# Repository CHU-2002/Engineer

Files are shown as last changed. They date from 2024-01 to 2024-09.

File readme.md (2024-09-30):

Most documents are written in Chinese and being translated to English by Google translation.

You will view a typical match in the following URL:[第57场 南方科技大学 ARTINX战队 vs华中科技大学 狼牙战队 RoboMaster 2023 超级对抗赛·区域赛（南部赛区）_哔哩哔哩_bilibili](https://www.bilibili.com/video/BV1iW4y197rk/?spm_id_from=333.788&vd_source=ce4e24e3ceb99b7799902f6719e723f6), in which the "Engineer" robot is No.2 of bule side.

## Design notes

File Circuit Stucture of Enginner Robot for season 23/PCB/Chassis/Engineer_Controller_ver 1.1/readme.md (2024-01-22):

Engineering master control update:

ver 1.0: Fixed the problem of 2482 being difficult to solder

 Fixed the problem of two LDOs connected in parallel

 Added slow start

 Added two can controllers

 Try to separate the power ground and signal ground

Ver 1.1: Fixed the problem of source-drain inversion during power-on slow start

Added silk

Be opened by Altium Designer

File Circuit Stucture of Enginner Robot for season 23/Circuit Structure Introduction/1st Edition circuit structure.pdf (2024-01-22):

## GH1.25-2p

## Tanks chain

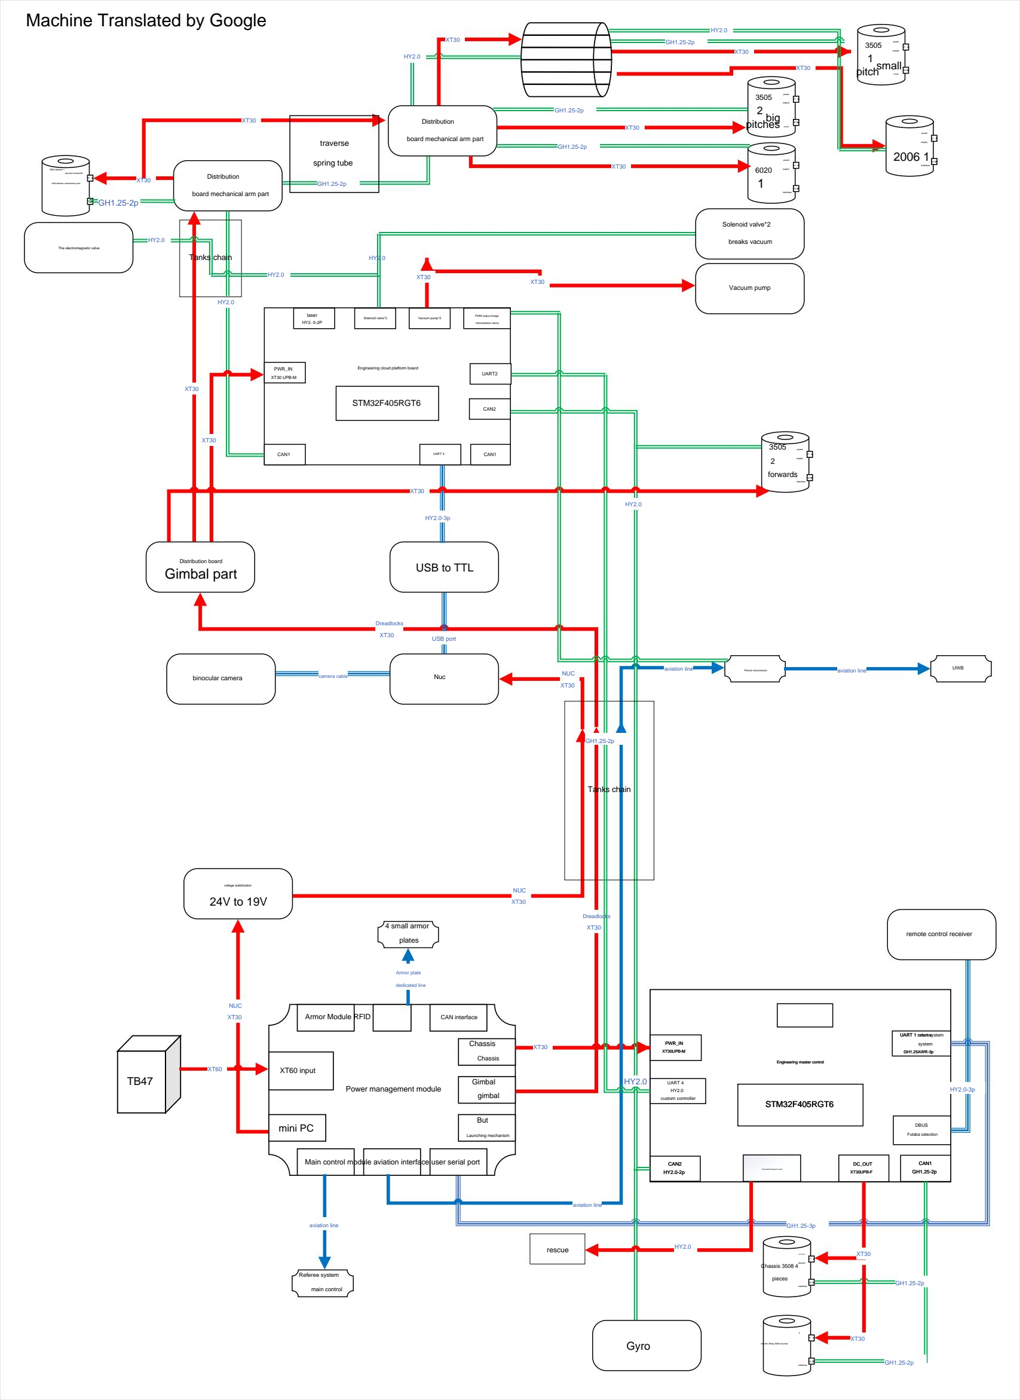
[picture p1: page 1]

XT30 UPB-M

HY2. 0-2P

PWM output image

transmission servo

CAN1

PWR_IN | UART2

laser

CAN2

CAN1

interface

source

3505 electric 1 source horizontal

shift electric connection port

interface

interface

interface

mouth

mouth

interface

### Chassis

CAN interface

Launching mechanism

### Armor Module RFID

### But

### XT60 input Gimbal

### gimbal

Chassis

### Main control module aviation interface user serial port

### 4 small armor

### plates

power

supply

power

supply

power

supply

power

supply

electricity

power

supply

2

electric lifting 3508 sources

HY2.0

Referee system

main control

Picture transmission | UWB

GH1.25-2p

HY2.0

HY2.0

GH1.25-2p

HY2.0

XT30

XT30

XT30

XT30

XT30

XT30

HY2.0

aviation line

camera cable
XT30

Dreadlocks

HY2.0

XT30

XT30

GH1.25-2p

GH1.25-2p

NUC

Dreadlocks

USB port

HY2.0-3p

GH1.25-3p

XT60

GH1.25-2p

aviation line

XT30

XT30

XT30

XT30

Armor plate

dedicated line

XT30

NUC

HY2.0-3p

aviation line NUC

HY2.0

GH1.25-2p

XT30

HY2.0

aviation line

XT30

XT30

XT30

GH1.25-2p

HY2.0

XT30

XT30

# mini PC

## STM32F405RGT6

### rescue

## Tanks chain

## traverse

## spring tube

# Gimbal part

# Gyro

Distribution board | USB to TTL

# 24V to 19V

## Power management module

TB47

binocular camera

voltage stabilization

remote control receiver

Solenoid valve*2

breaks vacuum

Distribution

board mechanical arm part

Vacuum pump

Nuc

The electromagnetic valve

Distribution

board mechanical arm part

## STM32F405RGT6

Engineering cloud platform board

H /L

H /L

H /L

H /L

+/-

+/-

+/-

+/-

+/-

+/-

+/-

H /L

+/-

H /L

H /L

H /L

Engineering master control control

3505

3505

6020

UART 4

Solenoid valve*3 | Vacuum pump*2

XT30UPB-M

Futaba selection

XT30UPB-F

XT30UPB-M | GH1.25AWR-3p GH1.25AWR-3p

DBUS

UART 4
HY2.0
custom controller

DC_OUT

PWR_IN

CAN1
GH1.25-2p GH1.25-2p

PWR_IN

CAN2
HY2.0-2p

The electromagnetic valve

UART 1 court referee system system

3505
2

## forwards

2006 1

Chassis 3508 4

pieces

# 1 small pitch

# 2 big pitches

1

# Machine Translated by Google

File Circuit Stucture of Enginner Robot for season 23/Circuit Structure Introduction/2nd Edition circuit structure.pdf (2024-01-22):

## referee system

6020

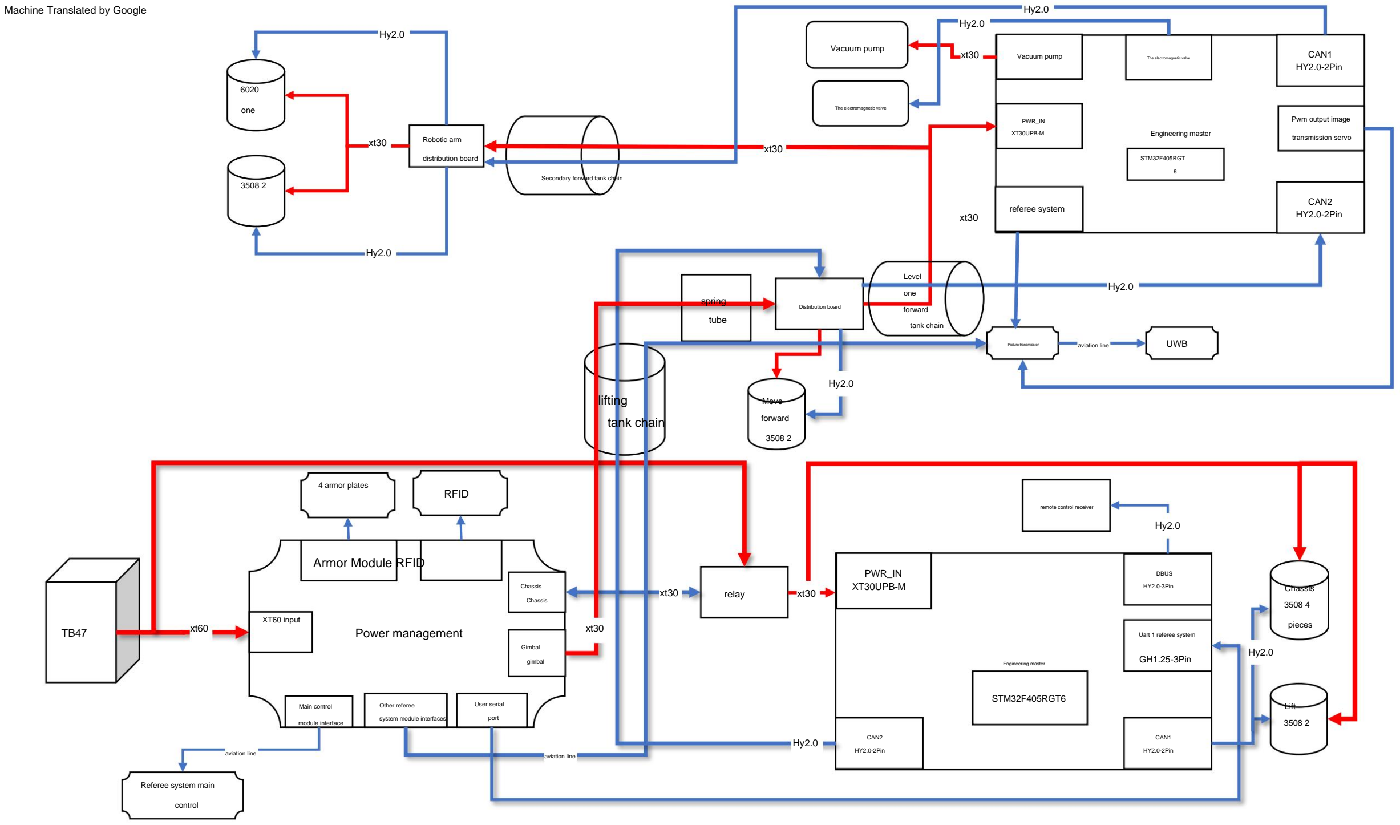
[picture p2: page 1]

## UWB

## spring

## tube

### Robotic arm

### distribution board

### Vacuum pump

### Engineering master

## Lift

3508 2

## Move

## forward

3508 2

## Chassis

3508 4

## pieces

## one

3508 2

The electromagnetic valve

### Pwm output image

### transmission servo

xt30

xt30

xt30

xt30

Picture transmission

## XT60 input

## 4 armor plates

## Referee system main

## control

TB47

The electromagnetic valve

# RFID

## Vacuum pump

# lifting tank chain

# Armor Module RFID

## relay

### Level

### one

### forward

### tank chain

Main control

module interface

Distribution board

Uart 1 referee system

CAN1

HY2.0-2Pin

PWR_IN

CAN2

HY2.0-2Pin

6

remote control receiver

Chassis

Chassis

STM32F405RGT

Other referee

system module interfaces

DBUS

HY2.0-3Pin

Engineering master

aviation line

Gimbal

gimbal

aviation line

XT30UPB-M

aviation line

xt60

Hy2.0

Hy2.0

Hy2.0

Hy2.0

Hy2.0

xt30

Hy2.0

User serial

port

xt30

Hy2.0

## XT30UPB-M

Secondary forward tank chain

Hy2.0

## PWR_IN

xt30

Hy2.0

# Power management

## GH1.25-3Pin

## CAN2 HY2.0-2Pin

## STM32F405RGT6

## CAN1 HY2.0-2Pin

# Machine Translated by Google

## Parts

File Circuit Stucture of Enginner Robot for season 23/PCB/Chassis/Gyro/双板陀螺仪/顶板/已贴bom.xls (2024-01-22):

元件名称 | 元件编号 | 封装规格 | 顶层位号 | 顶层数
2.2uF(225) ±20% 6.3V X5R | C12530 | 0402 | C3, C7 | 2
100KΩ (1003) ±1% | C25741 | 0402 | R8 | 1
150Ω (1500) ±1% | C22808 | 0603 | R1, R2, R3, R4, R5, R6 | 6
ICM-20602 | C97633 | LGA-16_3.0x3.0x0.5P_3+5 | U1 | 1
AO3400A | C20917 | SOT-23-3L | Q1 | 1
1KΩ (1001) ±1% | C11702 | 0402 | R7, R11 | 2
220nF (224) ±10% 16V X7R | C16772 | 0402 | C9 | 1
SC662K-3.3V | C83932 | SOT-23-3 | U3 | 1
QMC5883L | C976032 | LGA-16 | U2 | 1
4.7KΩ (4701) ±1% | C25900 | 0402 | R9, R10 | 2
100nF (104) ±10% 16V X7R | C1525 | 0402 | C1, C2, C4, C5, C6 | 5
4.7uF (475) ±20% 10V X5R | C23733 | 0402 | C8 | 1

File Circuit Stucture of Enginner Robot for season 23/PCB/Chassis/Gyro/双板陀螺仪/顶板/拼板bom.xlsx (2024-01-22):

Comment | Designator | Footprint
1k | R7, R11 | 0402
4.7k | R9, R10 | 0402
100k | R8 | 0402
150R | R1, R2, R3, R4, R5, R6 | 0603
NMOS | Q1 | SOT-23-3
Header 6 | P1, P2 | HEADER 6x1 _ 1.0mm
2.2uF | C3, C7 | 0402
4.7uF | C8 | 0402
100nF | C1, C2, C4, C5, C6 | 0402
220nF | C9 | 0402
ICM20602 | U1 | LGA-16
IST8310 | U2 | LGA16
LDO_SOT23-3 | U3 | SOT-23-3

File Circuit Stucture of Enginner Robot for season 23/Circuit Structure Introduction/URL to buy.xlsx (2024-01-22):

模块名称 | 购买链接
SMC端子/胶壳-电磁阀专用 | 【淘宝】https://m.tb.cn/h.fDcYZsZ?tk=VRfA2onmPXu「SMC电磁阀插头端子SY3120/3220/5120/7120/9120通用电源线束胶壳」 点击链接直接打开
光电传感器 | 【淘宝】https://m.tb.cn/h.fveGomt?tk=DKkI2onFeCM「M4M5M6M8微型激光漫反射光电开关可调可见光红外线感应传感器24v」 点击链接直接打开
激光测距（这一版车没有用到） | 【淘宝】https://m.tb.cn/h.fDcg0qm?tk=HwWN2onEhlG「正点原子串口激光测距模块MS53L0M MS53L1M距离传感器ToF测距仪」 点击链接直接打开
坦克链 | 【淘宝】https://m.tb.cn/h.fveNS0r?tk=8aMq2onlpT3「尼龙塑料钢铝拖链坦克链条静音桥式全封闭机械机床电缆保护穿线槽」 点击链接直接打开

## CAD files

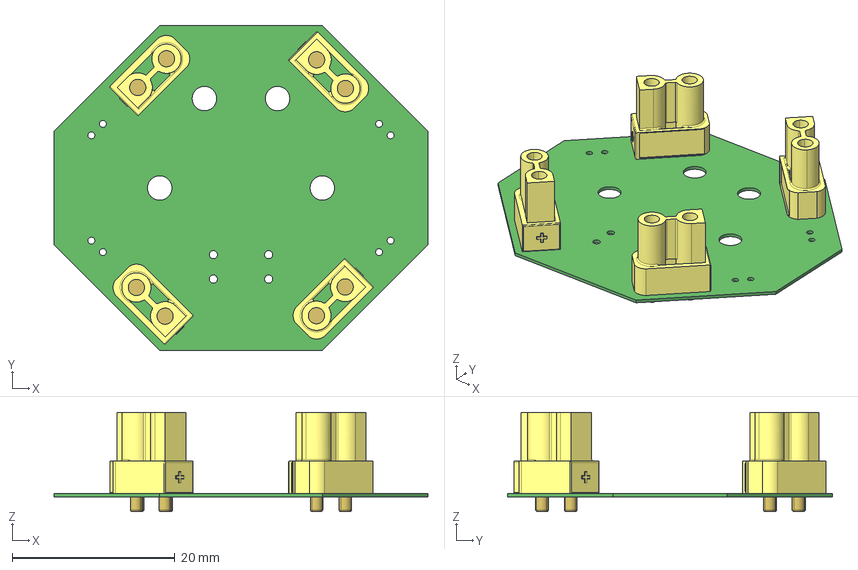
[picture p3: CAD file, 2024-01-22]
Circuit Stucture of Enginner Robot for season 23/PCB/Chassis/Centre_board/中心连接板.step
46.0 x 40.0 x 12.2 mm
Board
P16
P9
P15
P2
P4
P6
P7
P11
P12
P13
P14
XT30UPB x 4

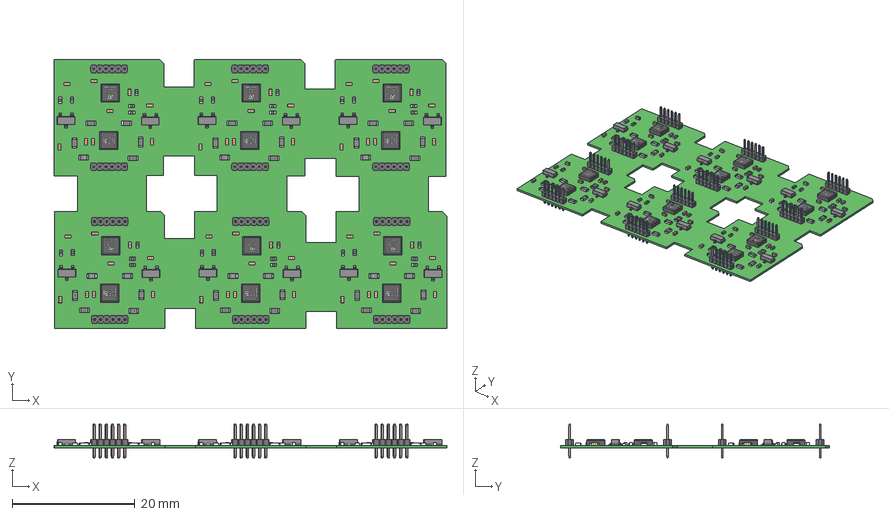
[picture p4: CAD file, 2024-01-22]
Circuit Stucture of Enginner Robot for season 23/PCB/Chassis/Gyro/双板陀螺仪/顶板/PCB3.step
64.1 x 43.9 x 5.50 mm
0402R x 30
sot23-3 x 12
0402C x 54
R_0603 x 36
LOGO? x 36
LGA16 x 12
pin x 72

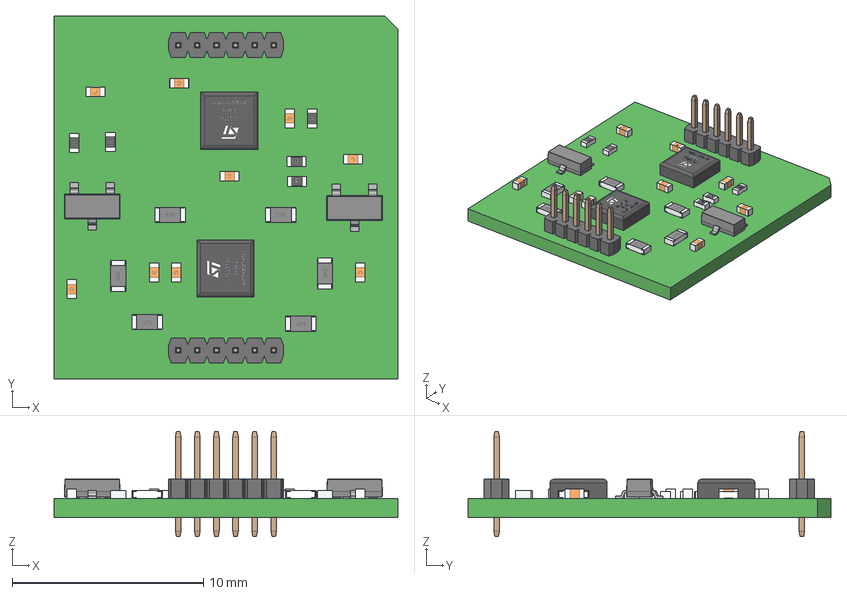
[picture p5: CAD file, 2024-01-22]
Circuit Stucture of Enginner Robot for season 23/PCB/Chassis/Gyro/双板陀螺仪/顶板/ICM20602+AK8975.step
18.0 x 19.0 x 5.50 mm
0402C x 9
0402R x 5
sot23-3 x 2
R_0603 x 6
LOGO? x 6
LGA16 x 2
pin x 12

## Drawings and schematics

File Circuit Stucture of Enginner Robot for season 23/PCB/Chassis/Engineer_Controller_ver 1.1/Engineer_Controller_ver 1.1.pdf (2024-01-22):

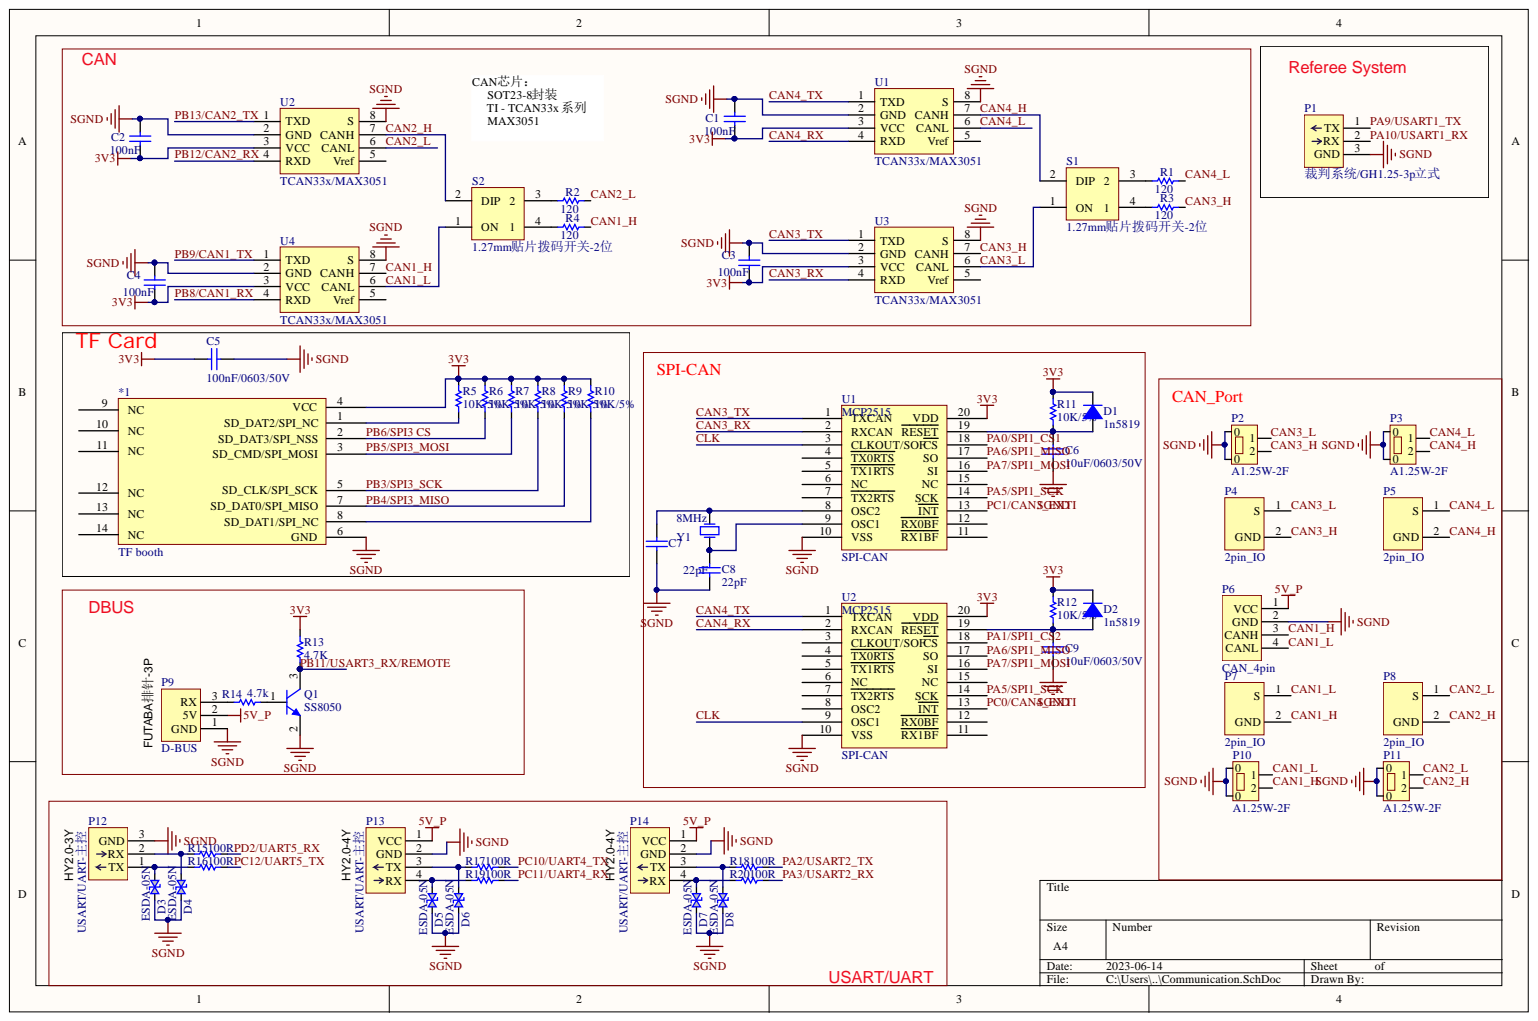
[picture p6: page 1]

VCC 3 | | CAN2_L

PB12/CAN2_RX

VCC 3

CAN3_RX

PB8/CAN1_RX

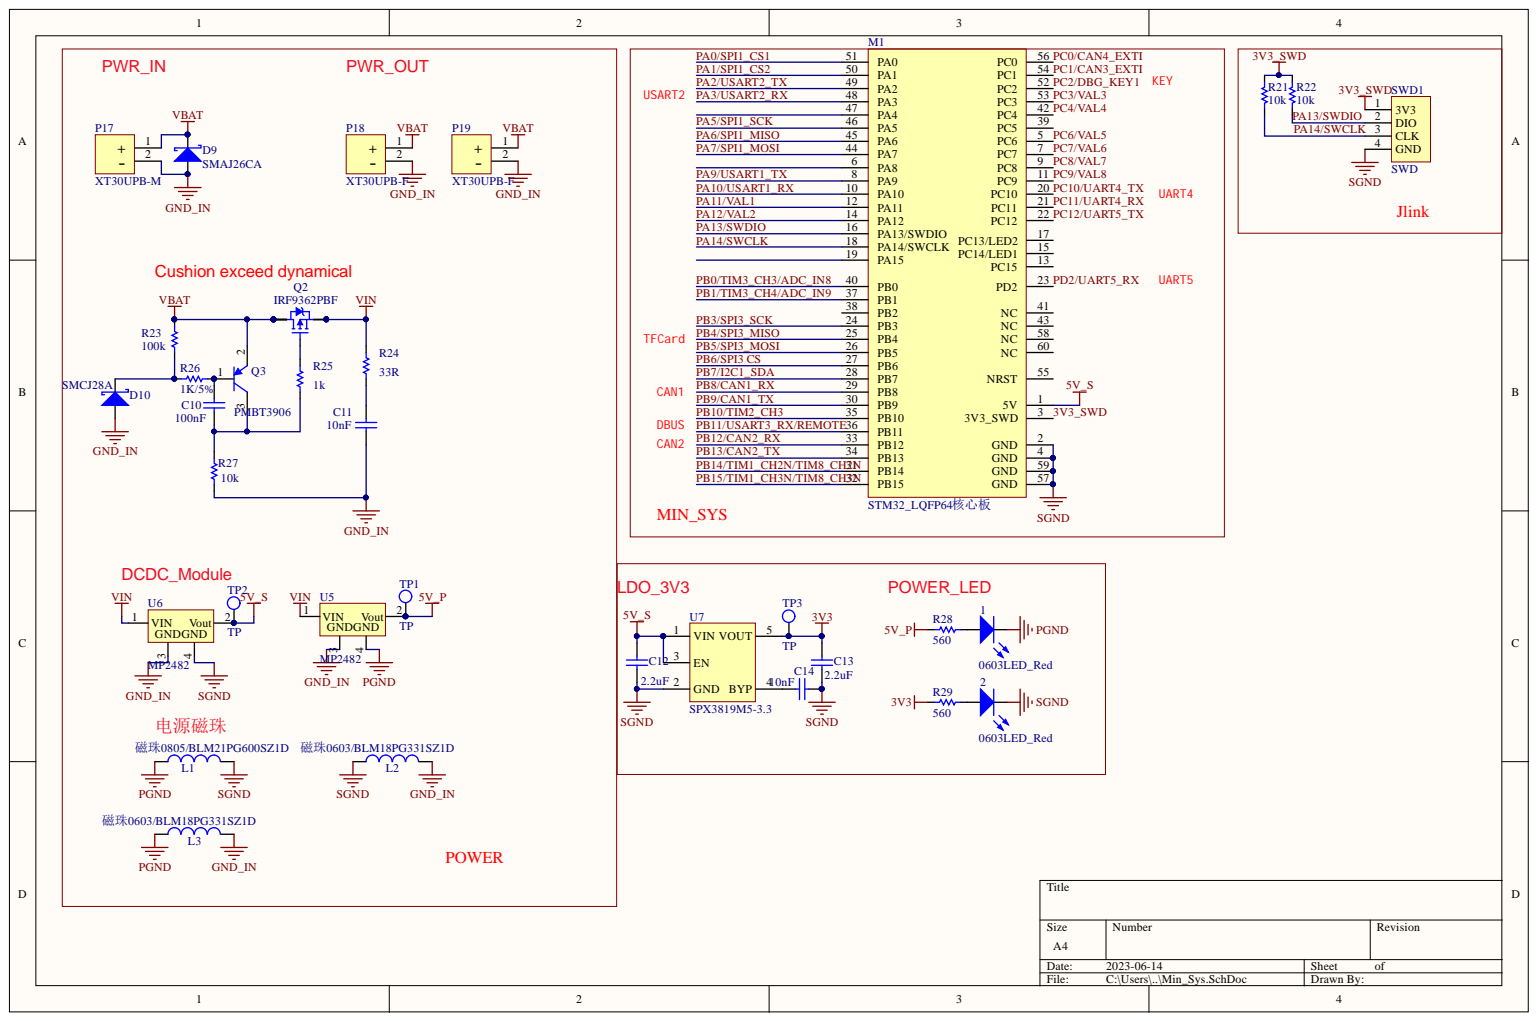
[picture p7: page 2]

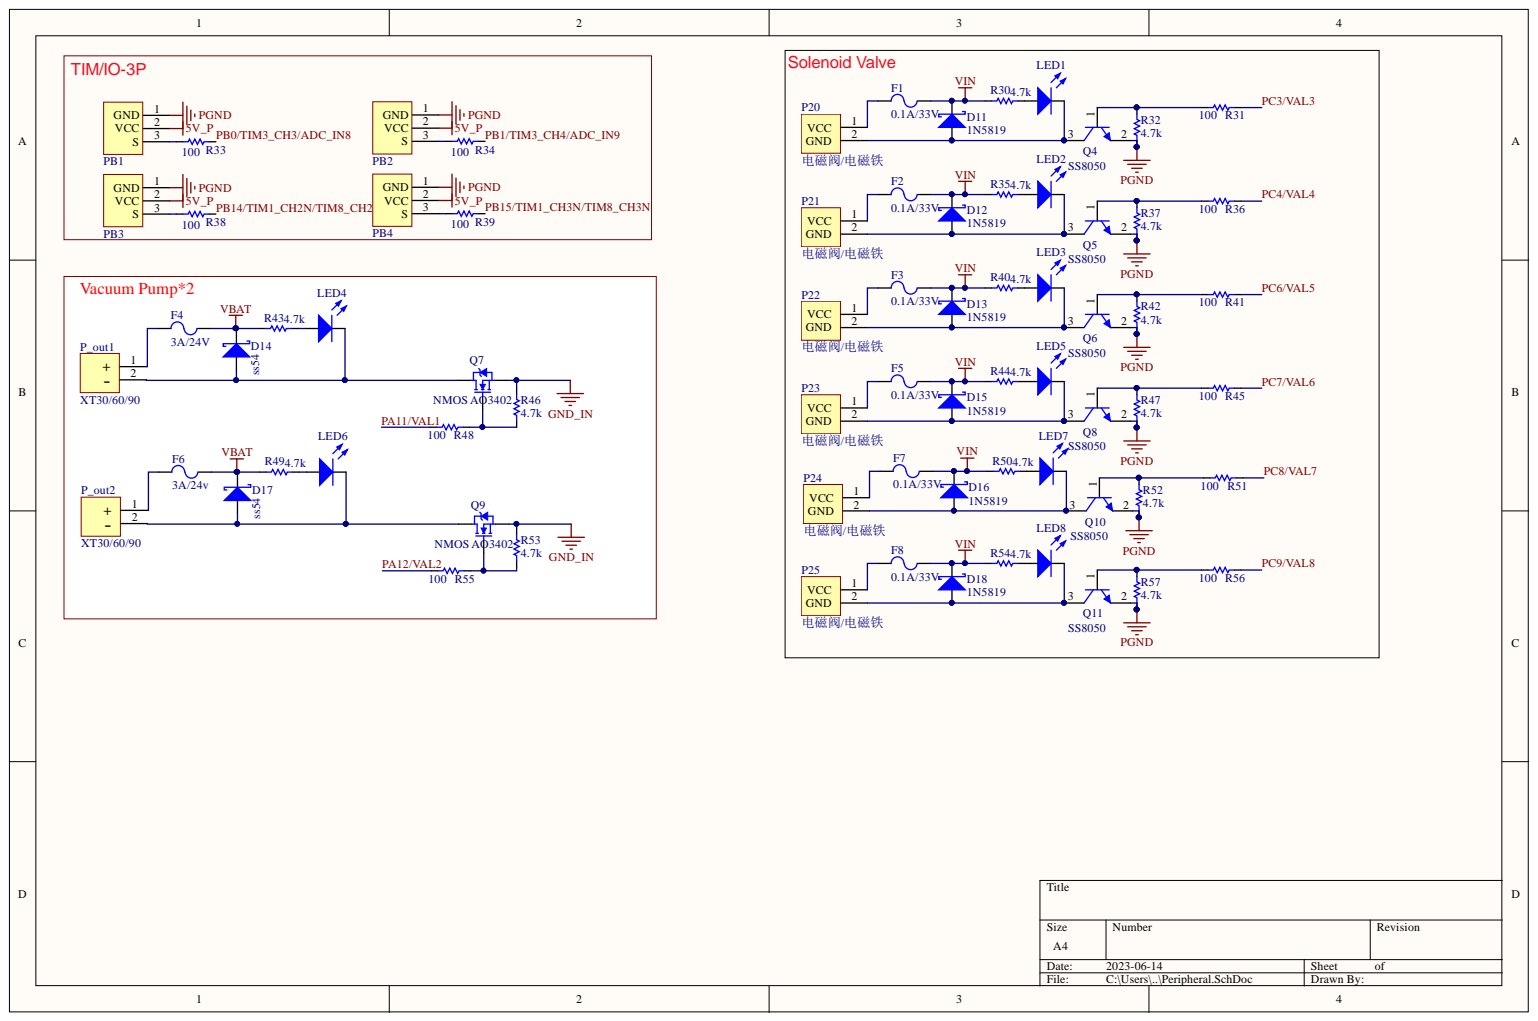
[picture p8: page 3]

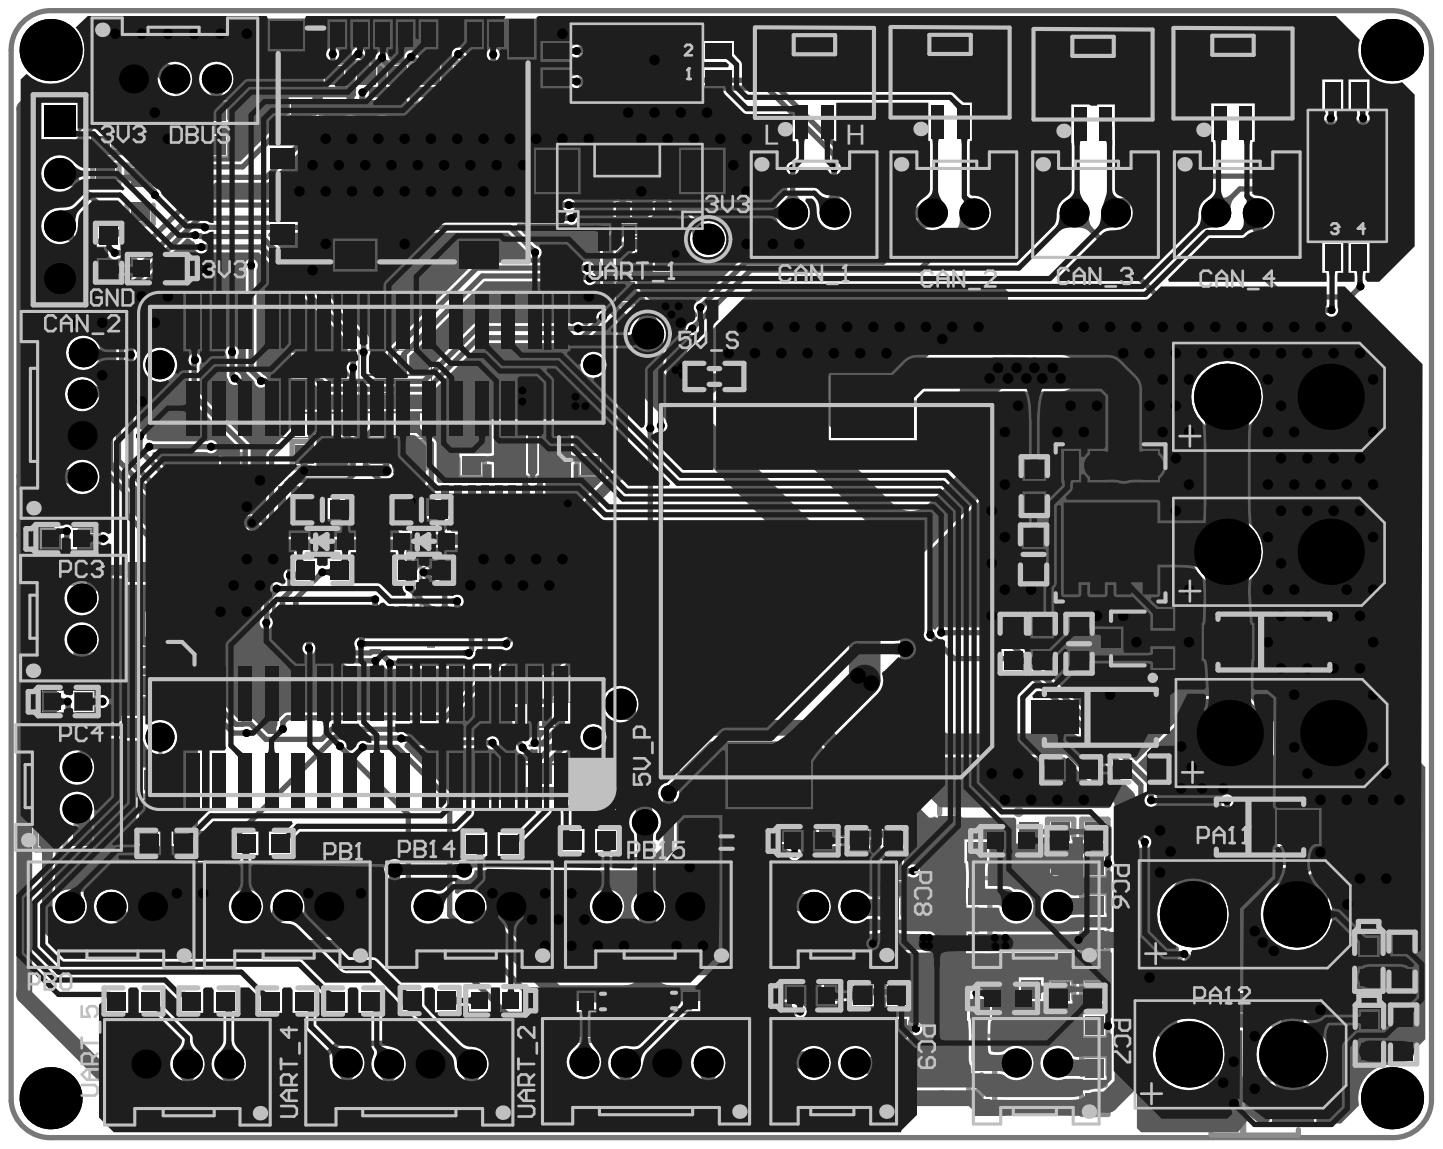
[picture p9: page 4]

# Board Stack Report

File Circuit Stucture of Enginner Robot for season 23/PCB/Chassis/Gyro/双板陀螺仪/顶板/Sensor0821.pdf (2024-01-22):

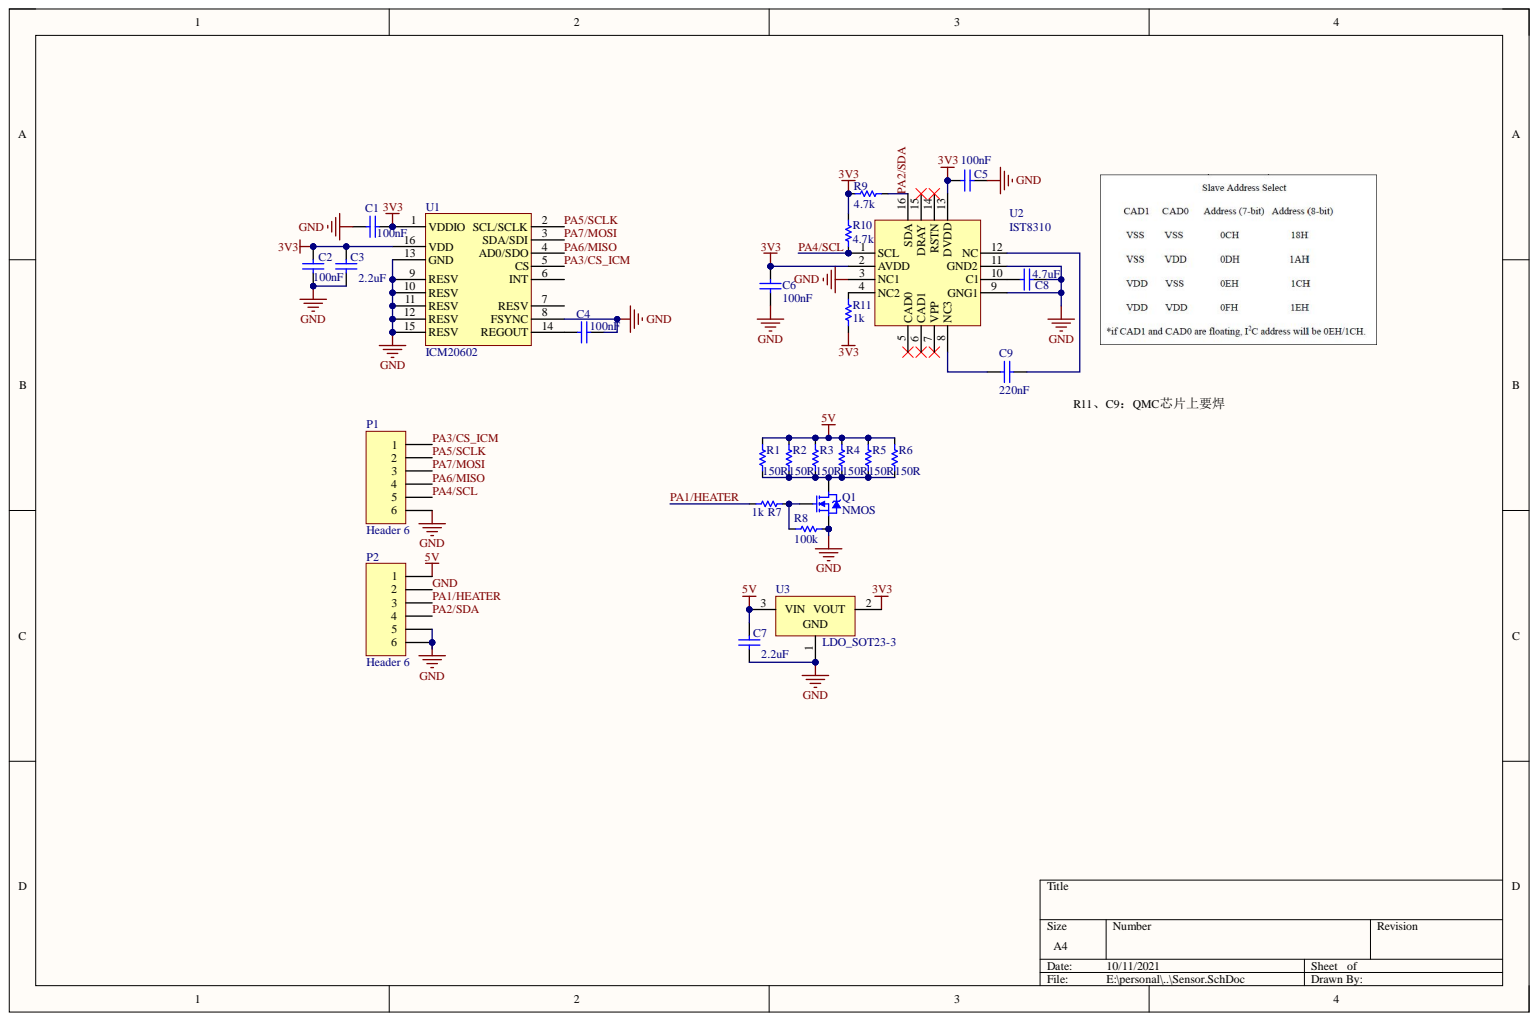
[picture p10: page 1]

NC3 8 GNG1 9 C1 10 GND2 11 NC 12 DVDD 13 RSTN 14 DRAY 15 SDA 16

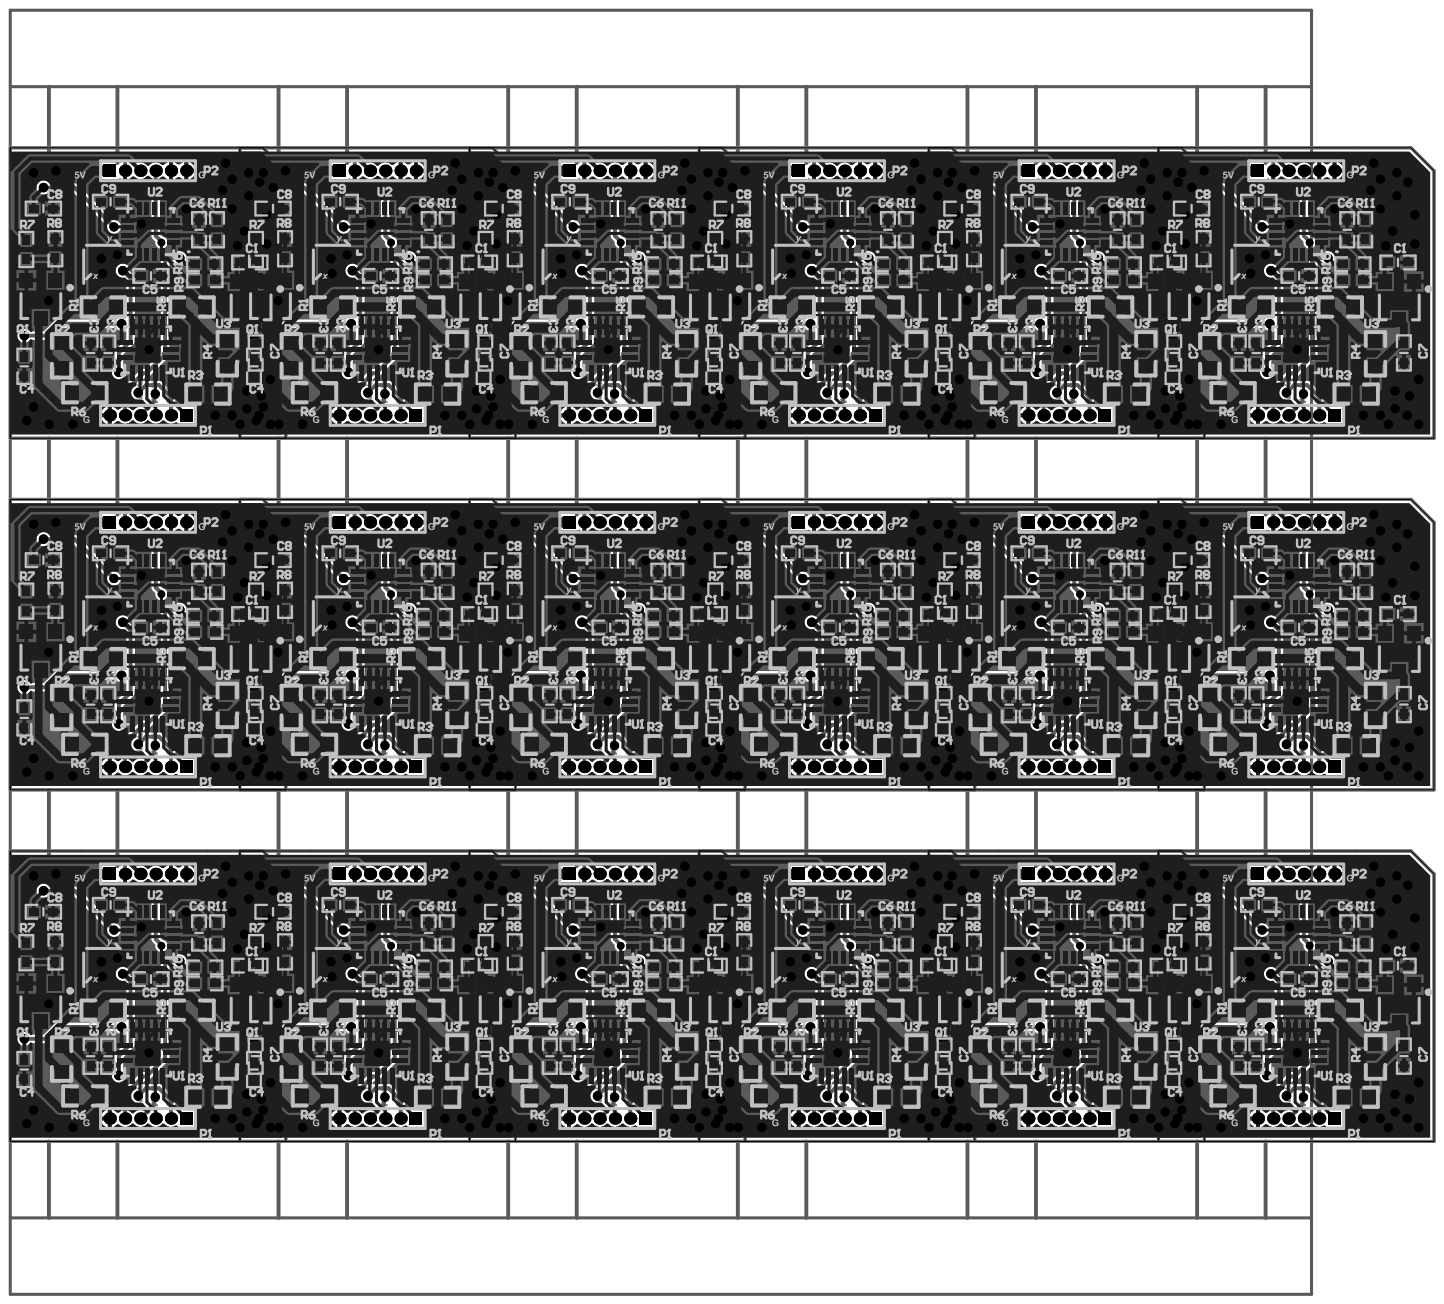
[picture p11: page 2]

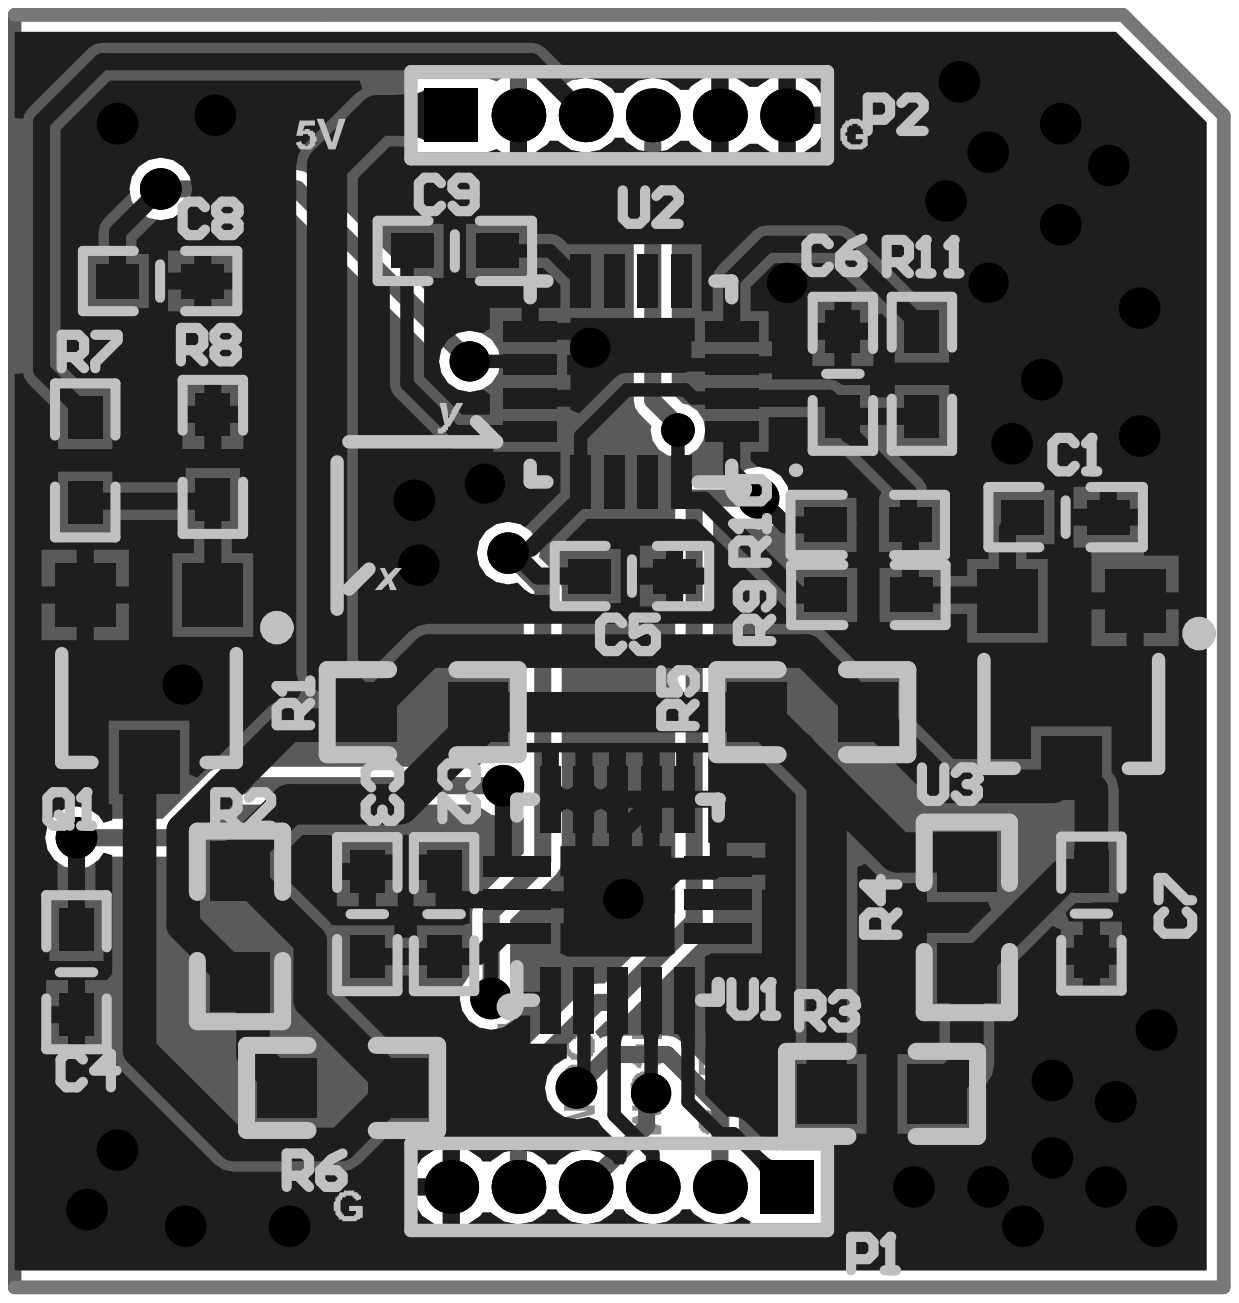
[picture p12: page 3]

Comment | Description | Designator | Footprint | LibRef | Quantity
100nF | Capacitor | C1, C2, C4, C5, C6 | 0402C | Cap | 5
2.2uF | Capacitor | C3, C7 | 0402C | Cap | 2
4.7uF | Capacitor | C8 | 0402C | Cap | 1
220nF | Capacitor | C9 | 0402C | Cap | 1
Header 6 | Header, 5-Pin | P1, P2 | HEADER 6x1 _ 1.0mm | Header 6 | 2
NMOS | N-Channel Power MOSFET | Q1 | SOT-23-3 | NMOS(SOT23 ) | 1
150R | Resistor | R1, R2, R3, R4, R5, R6 | 0603R | Res1 | 6
1k | Resistor | R7, R11 | 0402R | Res1 | 2
100k | Resistor | R8 | 0402R | Res1 | 1
4.7k | Resistor | R9, R10 | 0402R | Res1 | 2
ICM20602 | | U1 | LGA-16 | ICM20602 | 1
IST8310 | | U2 | LGA16 | IST8310 | 1
LDO_SOT23-3 | | U3 | SOT-23-3 | LDO_SOT23-3 | 1
